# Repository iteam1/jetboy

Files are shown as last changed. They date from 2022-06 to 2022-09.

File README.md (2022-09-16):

 

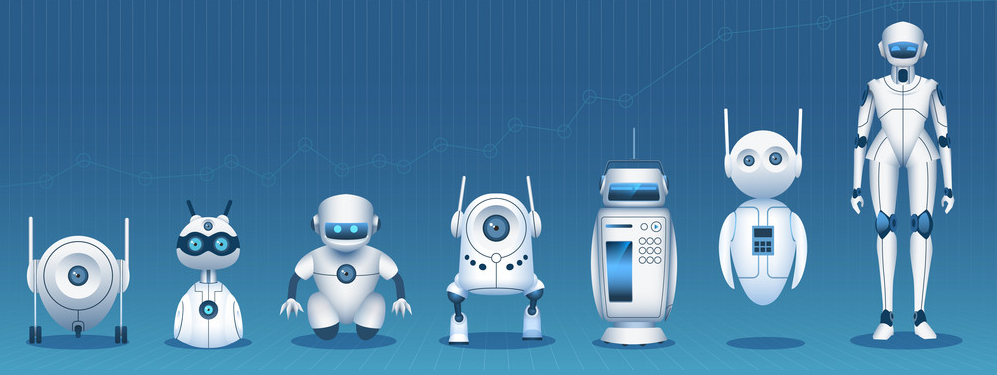
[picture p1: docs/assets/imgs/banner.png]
banner


### robot-jetboy

#### Quick-guide

**Step1** clone this repo `git clone git@github.com:iteam1/robot-jetboy.git`

**Step2** go to [init](/init) then follow the instruction for setting up the repository.

**Step3** run the entry point script `sudo bash root.sh --help`

To access the robot remotely linux-linux `ssh jetboy@<robot-internal-ip>` or [PuTTY](https://www.putty.org/)

*Note*

- [gpio.py](/gpio.py): control robot gpio

- [server.py](/server.py): build a local webserver for manually control

#### Online document

[offical-online-documents](https://iteam1.github.io/jetboy-docs/index-en.html)

#### Tools

|No|Tool|Description|
|---|---|---|
|1|[sublime-text](https://www.sublimetext.com/)|code editor|
|2|[diagrameditor](https://www.diagrameditor.com/)|drawing UML|
|3|[pixlr](https://pixlr.com/vn/x/)|design banner|
|4|[github](https://github.com/)|cloud platform for manage your project|
|5|[git](https://git-scm.com/)|control your repository|
|6|[ezgif](https://ezgif.com/maker)|ezgif maker|
|7|[symbolcopy](https://www.symbolcopy.com/)|get symbol character|
|8|[shields](https://shields.io/)|create your own git badges|
|9|[kleki](https://kleki.com/)|drawing sketch online|
    
#### References

[jetson-inference](https://github.com/dusty-nv/jetson-inference) | [examples](https://github.com/dusty-nv/jetson-inference/tree/master/examples) | [python](https://github.com/dusty-nv/jetson-inference/tree/master/python) | [plugins](https://github.com/dusty-nv/jetson-inference/tree/master/plugins) | [c](https://github.com/dusty-nv/jetson-inference/tree/master/c) | [convert to numpy array](https://github.com/dusty-nv/jetson-inference/issues/1118)

[libRealsense](https://github.com/IntelRealSense/librealsense) | [installLibrealsense](https://github.com/JetsonHacksNano/installLibrealsense)

[open3D](https://github.com/isl-org/Open3D)

[face-recognition](https://github.com/ageitgey/face_recognition)

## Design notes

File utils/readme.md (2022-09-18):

### repo utils

|Program|Description|Comment|
|---|---|---|
|[test_serial.py](/utils/test_serial.py)|test serial-communication with microcontroller arduino-nano, connect to serial port example: `COM4` on Windows or `dev/ttyUSB0`, give permission for serial port `sudo chmod a+rw /dev/ttyUSB0`|refer to embeded code [test_uart](https://github.com/iteam1/robot-jetboy/tree/main/embed/test_uart),[uart2uart](https://github.com/iteam1/robot-jetboy/tree/main/embed/uart2uart)|
|[read_db.py](/utils/read_db.py)|test serial-communication with arudino chip|`python3 -n 1 /utils/read_db.py`|
|[stream_d455.py](/utils/stream_d455.py)|test stream depth camera d455 by pyrealsense and opencv|depend on module [realsense_depth.py](/utils/realsense_depth.py)|
|[stream_cam.py](/utils/stream_cam.py)|test stream serial camera by opencv|list all camera on Linux `ls /dev/video*`|
|[test_sensor.py](/utils/test_sensor.py)|test ultra-sonic sensors signal||
|[rplidar.py](/utils/rplidar.py)|get info from serial RPlidar A1||
|[track_marker.py](/utils/track_marker.py)|control robot follow a target aruco-marker's id|required opencv-contrib for using aruco module, this package is no longer used in this repo, for reference purposes only|
|[view_cloud.py](/utils/view_cloud.py)|view a single point cloud file `.ply` file captured by depth camera||
|[pyrealsense2](/utils/pyrealsense2)|this is not a util program, if you want to use pyrealsense package installed by build from source C, you have to add this floder into the directory where you store the util program use pyrealsense, similar [realsense_depth.py](/utils/realsense_depth.py)||
|[test_motor.py](/utils/test_motor.py)|test motor controller||
|[detect_ports.py](/utils/detect_ports.py)|identify multi serial ports|list all port on linux `ls /dev/ttyUSB*`|
|[gpio_control.py](/utils/gpio_control.py)|intergate arm, emoled, and motor into a object and control via input||
|[face_rec.py](/utils/face_rec.py)|test face recognition function|`dlib` error,install command [here](https://github.com/iteam1/robot-jetboy/tree/main/init)|
|[blur_face_webcam.py](/utils/blur_face_webcam.py)|blur face by face_recognition||

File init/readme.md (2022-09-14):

### initialize-guide

**step1**: install a code-editor `bash sublime-text.sh`.

**step2**: install `python3-pip` package: `sudo apt-get update & sudo apt-get install python3-pip`.

**step3**: install python packages virtual enviroment `pip3 install virtualenv`.

**step4**: install pyrealsense for using D455 depth camera `bash pyrealsense.sh`. pyrealsense can not install normally by `pip3`.

**step5**: install opencv `sudo apt-get install python3-opencv` (stable version)

**step6**: install face-recognition `bash face_recognition.sh`.[issuses](http://www.open3d.org/docs/release/arm.html)

**step7**: install jetson-inference by this command `bash jetson-inference.sh`, **run it outsize this repo**.

**step8** : install open3d. [help](https://github.com/isl-org/Open3D/issues/2606#issuecomment-742760659) or Open3D provides experimental support for 64-bit ARM architecture (arm64 or aarch64) on Linux and macOS (Apple Silicon). refer to [ARM support](http://www.open3d.org/docs/release/arm.html).But first try this command:
     
     python3 -m pip install --upgrade pip
     sudo pip3 install open3d==0.13.0

**step9**: install the other required packages by in [requirements.txt](/init/requirements.txt) `pip3 install -r requirements.txt`.

these packages can be install normally by `pip3 install [package_name]`, [requirements.txt](/init/requirements.txt) contain the main packages and their dependencies, bellow is main packages you can install them manually by `pip3 install [package_name]`.

     flask
     flask_sqlalchemy
     sqlite3
     numpy
     pyserial

- export packages into requirements.txt: `pip3 freeze > requirements.txt`.

*Notes:* All packages,libraries and dependencies must be install in gobal. `RPi.GPIO` is build-in package and only can be install on embedded-hardwares like jetson-board or raspberry-board.

**bash-scripts table**

|No|Script|Description|Comment|
|---|---|---|---|
|01|[sublime-text.sh](/init/sublime-text.sh)|install code editor sublime-text|*required*|
|02|[pyrealsense.sh](/init/pyrealsense.sh)|install pyrealsense python library|*required*|
|03|[face_recognition.sh](/init/face_recognition.sh)|install pyrealsense python library|*required*|
|04|[opencv-contrib.sh](/init/opencv-contrib.sh)|install opencv-contrib version for jetson-nano, build from source||
|05|[tensorflow.sh](/init/tensorflow.sh)|install tensorflow for jetson-nano||
______

#### init database

the database `sqlite3` is already there in the repo, but if you lost it, in `/utils` folder Run python script for generate a sqlite database: `python3 robot/gendata.py`, this command will create a datbase and a table. Then open terminal and add a row into that table:

	from robot import db
	from robot.models import Robot
	robot = Robot()
	db.session.add(robot)
	db.session.commit()
______

#### setup for lidar sensor

add permission for connecting to serial port `/dev/ttyUSB0` permission denied, `username =  jetboy`. `portname = /dev/ttyUSB0` by: `sudo usermod -a -G dialout <username> & sudo chmod a+rw <portname>`

connect to lidar serial port:

     sudo su
     cd /
     cd dev
     chown <username> ttyUSB0

or:

     cd /dev
     ls t*
     sudo usermod -a -G dialout $USER
______

#### backup and restore os-system

go to `\` as `super user`

     sudo su
     cd /

run command to create backup.tar.gz file

     sudo tar czf /backup.tar.gz\
      --exclude=/backup.tar.gz\
      --exclude=/bin\
      --exclude=/boot\
      --exclude=/dev\
      --exclude=/dist-packages\
      --exclude=/lib\
      --exclude=/lost+found\
      --exclude=/media\
      --exclude=/mnt\
      --exclude=/opt\
      --exclude=/proc\
      --exclude=/root\
      --exclude=/run\
      --exclude=/sbin\
      --exclude=/snap\
      --exclude=/srv\
      --exclude=/sys\
      --exclude=/tmp\
      --exclude=/usr\
      --exclude=/var\
      /

make sure you are root and that you and the backup file are in the root of the filesystem `tar xvpfz backup.tar.gz -C /`
______

#### access robot remotely

- you can use ssh software like PuTTY or if using linux, this os-system is already support ssh into another linux-machine: `ssh [machine_name]@[machine_lan_ip]`, example: `ssh jetboy@192.168.1.9`
______

#### give permission for serial port

if you want to gibve permission for serial port `/dev/ttyUSB0`: `sudo chmod a+rw /dev/ttyUSB0`

### check JetPack version

if you want to check your JetPack verison `sudo apt-cache show nvidia-jetpack`
for the version specifically `sudo apt-cache show nvidia-jetpack | grep "Version"`

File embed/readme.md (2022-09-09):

### embedded source code

|No|Program|Description|Comment|
|---|---|---|---|
|01|[CODE_ARM_ROBOT2](/embed/CODE_ARM_ROBOT2)|robot arm arduino-nano source code|version2|
|02|[CODE_ARM_ROBOT3](/embed/CODE_ARM_ROBOT3)|robot arm arduino-nano source code|version3|
|03|[sketch_nov26a](/embed/sketch_nov26a)|arudino-nano read ultra sensors's signal||
|04|[sketch_oct31g](/embed/sketch_oct31g)|test motor driver BTS960||
|05|[test_uart](/embed/test_uart)|test uart commnication between main board and chip arduino by builtin-port|refer to python code [test_serial.py](https://github.com/iteam1/robot-jetboy/blob/main/utils/test_serial.py)|
|06|[uart2uart](/embed/uart2uart)|test uart commnication between main board and chip arduino by softserial library|refer to python code [test_serial.py](https://github.com/iteam1/robot-jetboy/blob/main/utils/test_serial.py)|
|07|[TEST_SERVO_STEP_EEPROM_Serial_Timer2US](/embed/TEST_SERVO_STEP_EEPROM_Serial_Timer2US)|test step-motor with timer-interrupt||
|08|[CODE_ARM_ROBOT](/embed/CODE_ARM_ROBOT)|robot arm arduino-nano source code but not be used anymore||
|09|[Blink](/embed/Blink)|test arduino nano clip with basic program blink build-in led||
|10|[Sweep](/embed/Sweep)|test RC servo, control servo rotate from a minimum angle to maximum angle||
|11|[Stepper](/embed/Stepper)|test Step motor, control rotate from a minimum angle to maximum angle||
|12|[Stepper2](/embed/Stepper2)|test Step motor, control rotate from a minimum angle to maximum angle by delayMicrosecond||
|13|[Code_LED_64_RGB](/embed/Code_LED_64_RGB),dependence [NeoPixel](https://github.com/adafruit/Adafruit_NeoPixel)|Emotional LED||
|14|[emoled](/embed/emoled)|Emotional LED customized,dependence [NeoPixel](https://github.com/adafruit/Adafruit_NeoPixel)|using|
|15|[arm](/embed/arm)||using|

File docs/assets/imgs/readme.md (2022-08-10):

|No|Image|Description|Comment|
|---|---|---|---|
|01|[banner](/docs/assets/imgs/banner.png)|repo banner|---|
|02|[img1](/docs/assets/imgs/img1.png)|Jetson Nano B01 pinout|---|
|03|[img2](/docs/assets/imgs/img2.png)|Jetson Nano B01 layout|---|
|04|[img3](/docs/assets/imgs/img3.png)|Arduino Nano control robot's arm|---|
|05|[img4](/docs/assets/imgs/img4.png)|Robot's arm wiring diagram|[detail](https://nshopvn.com/product/mach-dieu-khien-dong-co-buoc-tb6600-4-0a-942vdc/)|
|06|[img5](/docs/assets/imgs/img5.png)|Robot's motor driver|[detail](https://nshopvn.com/product/mach-dieu-khien-dong-co-dc-bts7960-43a-1-dong-co/)|
|07|[img6](/docs/assets/imgs/img6.png)|TB6600 step motor driver|[detail](https://nshopvn.com/product/mach-dieu-khien-dong-co-buoc-tb6600-4-0a-942vdc/)|
|08|[img7](/docs/assets/imgs/img7.png)|Voltage-Ampere metter 5-28VDC with internal source|---|
|09|[img8](/docs/assets/imgs/img8.png)|Voltage-Ampere metter 0-100VDC with external source|---|
|10|[img9](/docs/assets/imgs/img9.png)|schematic|---|
|11|[img10](/docs/assets/imgs/img10.png)|PL2303-Arduino Serial communication|---|
|12|[img11](/docs/assets/imgs/img11.png)|Emotional LED|---|

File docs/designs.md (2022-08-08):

### UMLs and sketchs of the repo

this table bellow give you the overview about repo's sketchs and UML.

|No|Name|Description|Comment|
|---|---|---|---|
|01|[sketch1](/docs/assets/sketchs/sketch1.pdf)|robot's electrical system overview|---|
|02|[uml1](/docs/assets/umls/UML1.xml)|describe how local-server, gpio module local database workflow|open with [diagrameditor](https://www.diagrameditor.com/)|
|03|[uml2](/docs/assets/umls/uml2.xml)|describe testing procedure|---|
|04|[uml3](/docs/assets/umls/uml3.xml)|describe how to control continously moving|this idea is not apply right now|
|05|uml4|describe how gpio-controller and  database work|---|
|06|[sketch2](/docs/assets/sketchs/sketch2.pdf)|robot's arm schematic,coordinate|---|
|07|[sketch2.1](/docs/assets/sketchs/sketch2.1.pdf)|robot's arm driver wiring,setting up|---|
|08|uml5|robot's arm workflow,protocol|---|
|09|sketch3|describe robot's motors,wiring,workflow,protocol|---|
|10|sketch4|describe robot's emotional-led,wiring,workflow,protocol|---|
|11|sketch5|describe robot's sensors,wiring,workflow,protocol|---|

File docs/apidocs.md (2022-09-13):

### APIdocs

1. [Home](#Home)
2. [Stream color frame](#Stream-color-frame)
3. [Stream depth frame](#Stream-depth-frame)
4. [Stream both frames](#Stream-both-frames)
5. [Manual](#Manual)
6. [Content](#Content)
7. [Emotion](#Emotion)
8. [Image](#Image)
9. [Estop](#Estop)
10. [Capture image](#Capture-image)
11. [Capture pointcloud](#Capture-pointcloud)
12. [Shutdown](#Shutdown)
13. [Get camera](#Get-camera)
14. [Face recogition](#Face-recognition)

## Home
[go back](#APIdocs)
<details><summary>click to expand</summary>
<p>

  Home page
* **URL:** `/`
* **Method:** `GET`
*  **URL Params:**
   **Required:**`None`
   **Optional:**`None`
* **Query Params:**`None`
* **Success Response:**
  * **Code:** 200 <br />
    **Content:** `home.html`
* **Error Response:**
  * **Code:** `None` <br />
    **Content:** `None`
* **Sample Call:**
* **Notes:**
  Check server is alive or not.
</p>
</details>

## Stream color frame
[go back](#APIdocs)
<details><summary>click to expand</summary>
<p>

  Response color frame from depth camera
* **URL:** `/color`
* **Method:** `GET`
*  **URL Params:**
   **Required:**`None`
   **Optional:**`None`
* **Query Params:**`None`
* **Success Response:**
  * **Code:** `None` <br />
    **Content:** streaming color frame
* **Error Response:**
  * **Code:** `None` <br />
    **Content:** `None`
* **Sample Call:**
* **Notes:**
  Get color frame of depth camera real-time
</p>
</details>

## Stream depth frame
[go back](#APIdocs)
<details><summary>click to expand</summary>
<p>

  Response depth frame from depth camera
* **URL:** `/depth`
* **Method:** `GET`
*  **URL Params:**
   **Required:**`None`
   **Optional:**`None`
* **Query Params:**`None`
* **Success Response:**
  * **Code:** `None` <br />
    **Content:** streaming depth frame
* **Error Response:**
  * **Code:** `None` <br />
    **Content:** `None`
* **Sample Call:**
* **Notes:**
  Get depth frame of depth camera real-time
</p>
</details>

## Stream both frames
[go back](#APIdocs)
<details><summary>click to expand</summary>
<p>

  Response depth frame and color frame stack together
* **URL:** `/both`
* **Method:** `GET`
*  **URL Params:**
   **Required:**`None`
   **Optional:**`None`
* **Query Params:**`None`
* **Success Response:**
  * **Code:** `None` <br />
    **Content:** depth frame and color frame of depth camera
* **Error Response:**
  * **Code:** `None` <br />
    **Content:** `None`
* **Sample Call:**
* **Notes:**
  Get depth frame and color frame of depth camera real-time
</p>
</details>

## Manual
[go back](#APIdocs)
<details><summary>click to expand</summary>
<p>

  Return a GUI as manual panel for controlling
* **URL:** `/manual`
------
* **Method:** `GET`
*  **URL Params:**
   **Required:**`None`
   **Optional:**`None`
* **Query Params:**`None`
* **Success Response:**
  * **Code:** 200 <br />
    **Content:** `manual.html`
* **Error Response:**
  * **Code:** `None` <br />
    **Content:** `None`
* **Sample Call:**
* **Notes:**
  `estop` value in database will be readed and update in `manual.html` template as by `jinja2`
------
* **Method:** `POST`
*  **URL Params:**
   **Required:**`None`
   **Optional:**`None`
* **Query Params:**`None`
* **Web Form:**
```
<form action = "{{ url_for('manual') }}" method = 'POST'>
  <input type = 'hidden' name = 'command' id = 'command'  value = [your-command]>
  <button class="btn btn-primary">&#8593;</button>
</form>
```
* **Success Response:**
  * **Code:** 301 <br />
    **Content:** Redirect to `manual.html`
* **Error Response:**
  * **Code:** 401 <br />
    **Content:** 401,Command Not Found
* **Sample Call:**
* **Notes:**
  `estop` value in database will be readed and update in `manual.html` template as by `jinja2`
</p>
</details>

## Content
[go back](#APIdocs)
<details><summary>click to expand</summary>
<p>

  Update content in database
* **URL:** `/content`
* **Method:** `POST`
*  **URL Params:**
   **Required:**`None`
   **Optional:**`None`
* **Query Params:**`None`
* **Web Form:**
```
 <form action = "{{ url_for('content') }}" method = 'POST'>
  <input class="form-control form-control-lg" type="text" placeholder = "What you wanna say?" name = "content">
  <small class="form-text text-muted">.</small>     
  <button type="submit" class="btn btn-primary mb-2">say it!</button>
</form> 
```
* **Success Response:**
  * **Code:** 200 <br />
    **Content:** Render `manual.html` template
* **Error Response:**
  * **Code:** `None` <br />
    **Content:** `None`
* **Sample Call:**
* **Notes:**
  `estop` value in database will be readed and update in `manual.html` template as by `jinja2`
</p>
</details>

## Emotion
[go back](#APIdocs)
<details><summary>click to expand</summary>
<p>

  Update Emotiton in database
* **URL:** `/emotion`
* **Method:** `POST`
*  **URL Params:**
   **Required:**`None`
   **Optional:**`None`
* **Query Params:**`None`
* **Web Form:**
```
<form action = "{{ url_for('emotion') }}" method = 'POST'>
  <input type = 'hidden' name = 'emotion' value = '[your-emotion]'>
  <button type="submit" class="btn btn-secondary" style="font-size:50px">&#128564;</button>
</form>
```
* **Success Response:**
  * **Code:** 200 <br />
    **Content:** Render `manual.html` template
* **Error Response:**
  * **Code:** `None` <br />
    **Content:** `None`
* **Sample Call:**
* **Notes:**
  `estop` value in database will be readed and update in `manual.html` template as by `jinja2`,emotion display a .gif
</p>
</details>

## Image
[go back](#APIdocs)
<details><summary>click to expand</summary>
<p>

  Update Image in database
* **URL:** `/image`
* **Method:** `POST`
*  **URL Params:**
   **Required:**`None`
   **Optional:**`None`
* **Query Params:**`None`
* **Web Form:**
```
<form action = "{{ url_for('image') }}" method = 'POST'>
  <input type = 'hidden' name = 'image' value = 'straightface'>
  <button type="submit" class="btn btn-secondary" style="font-size:50px">&#128528;</button>
</form>
```
* **Success Response:**
  * **Code:** 200 <br />
    **Content:** Render `manual.html` template
* **Error Response:**
  * **Code:** `None` <br />
    **Content:** `None`
* **Sample Call:**
* **Notes:**
  `estop` value in database will be readed and update in `manual.html` template as by `jinja2`, image display a .png or .jpg file.
</p>
</details>

## Estop
[go back](#APIdocs)
<details><summary>click to expand</summary>
<p>

  Update estop value in database, if estop=0 update estop=1 else udpate estop=0
* **URL:** `/estop`
* **Method:** `POST`
*  **URL Params:**
   **Required:**`None`
   **Optional:**`None`
* **Query Params:**`None`
* **Web Form:**
```
<form action = "{{ url_for('estop') }}" method = 'POST'>
  <small class="form-text text-muted">.</small>
  <p class = 'text-center'>
      {% if estop == True %}
          <button type="Estop" class="btn btn-danger mb-4">ESTOP</button>
      {% else %}
          <button type="Estop" class="btn btn-primary mb-6">ESTOP</button>
      {% endif %}
  </p>
</form>
```
* **Success Response:**
  * **Code:** 200 <br />
    **Content:** Render `manual.html` template
  * **Code:** 201 <br />
    **Content:** Render `manual.html` template
* **Error Response:**
  * **Code:** `None` <br />
    **Content:** `None`
* **Sample Call:**
* **Notes:**
  Color of estop button will change, blue if estop=0 red if estop=1
</p>
</details>

## Capture image
[go back](#APIdocs)
<details><summary>click to expand</summary>
<p>

  Capture current frame of robot's camera
* **URL:** `/capture_img`
* **Method:** `POST`
*  **URL Params:**
   **Required:**`None`
   **Optional:**`None`
* **Query Params:**`None`
* **Web Form:**
```
<form action = "{{ url_for('capture_img') }}" method = 'POST'>
    <input type = 'hidden' name = 'capture image'>
    <button class="btn btn-primary mb-2">cap img</button>
</form>
```
* **Success Response:**
  * **Code:** 200 <br />
    **Content:** Render `manual.html` template
* **Error Response:**
  * **Code:** `None` <br />
    **Content:** `None`
* **Sample Call:**
* **Notes:**
  `estop` value in database will be readed and update in `manual.html` template as by `jinja2`
</p>
</details>

## Capture pointcloud
[go back](#APIdocs)
<details><summary>click to expand</summary>
<p>

  Capture current pointcloud (depth-frame) of robot's camera
* **URL:** `/capture_pointcloud`
* **Method:** `POST`
*  **URL Params:**
   **Required:**`None`
   **Optional:**`None`
* **Query Params:**`None`
* **Web Form:**
```
<form action = "{{ url_for('capture_pointcloud') }}" method = 'POST'>
  <input type = 'hidden' name = 'capture pointcloud'>
  <button class="btn btn-primary mb-2">cap pointcloud</button>
</form>
```
* **Success Response:**
  * **Code:** 200 <br />
    **Content:** Render `manual.html` template
* **Error Response:**
  * **Code:** `None` <br />
    **Content:** `None`
* **Sample Call:**
* **Notes:**
  `estop` value in database will be readed and update in `manual.html` template as by `jinja2`
</p>
</details>

## Shutdown
[go back](#APIdocs)
<details><summary>click to expand</summary>
<p>

  Shutdown robot's local flask server
* **URL:** `/shutdown`
* **Method:** `POST`
*  **URL Params:**
   **Required:**`None`
   **Optional:**`None`
* **Query Params:**`None`
* **Web Form:**
```
<form action = "{{ url_for('shutdown') }}" method = 'POST'>
  <button class="btn btn-danger mb-2">shutdown server</button>
</form>
```
* **Success Response:**
  * **Code:** 200 <br />
    **Content:** 'Server shutting down'
* **Error Response:**
  * **Code:** `None` <br />
    **Content:** `None`
* **Sample Call:**
* **Notes:** `None`
</p>
</details>

## Get camera
[go back](#APIdocs)
<details><summary>click to expand</summary>
<p>

  Response serial-camera frame
* **URL:** `/camera`
* **Method:** `GET`
*  **URL Params:**
   **Required:**`None`
   **Optional:**`None`
* **Query Params:**`None`
* **Success Response:**
  * **Code:** `None` <br />
    **Content:** streaming frame of serial-camera
* **Error Response:**
  * **Code:** `None` <br />
    **Content:** `None`
* **Sample Call:**
* **Notes:**
  Get color `RGB` frame of serial-camera real-time, function's name in `routes.py` `get_cam`, Only one device can get the response, An other need to wait until finish, can not share `cv2.VideoCapture()` streaming data
</p>
</details>

## Face recognition
[go back](#APIdocs)
<details><summary>click to expand</summary>
<p>

  Response face-recognition detected by serial-camera
* **URL:** `/faces`
* **Method:** `GET`
*  **URL Params:**
   **Required:**`None`
   **Optional:**`None`
* **Query Params:**`None`
* **Success Response:**
  * **Code:** `None` <br />
    **Content:** streaming detected face on frame of serial-camera
* **Error Response:**
  * **Code:** `None` <br />
    **Content:** `None`
* **Sample Call:**
* **Notes:**
  face-recognition application, function's name in `routes.py` `get_face`, Only one device can get the responsem An other need to wait until finish, can not share `cv2.VideoCapture()` streaming data
</p>
</details>

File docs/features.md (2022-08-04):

## robot's features & change logs

new features and change logs will be write down in this document

### 31-July-22

**1/ Power supply and electrical system**

- Main power supply is 6Ah-12VDC litium battery (chargeable)
- Voltage and Current metter

*Note:* the current consumption can be increase when boot up, `over current throtted` warning will display on screen and yellow power led on main board blink, that's beacause depth camera d455 consump alot current of main-board jetson nano. The total current can between 0-10 Ampere if only running main-board and 20-30 Ampere when robot's motor run.

**2/ Visual intelligence**

- Depth camera D455 (Intel Realsense)

      -Components	
            - Intel RealSense D4
            - Module Intel RealSense D450
            - Bosch BMI055 IMU
      - Viewspace	86° × 57° (+/- 3°)
      - Resolution	
            - 1280 × 720 @ 30fps
            - 848 × 480 @ 90fps
      - Frame per second:	Up to 90 fps
      - Minimum Depth Distance (Min-Z: 40 cm
      - Sensor Shutter Type: Global Shutter
      - Recommended Range: From 0.4 to 6 m
      - Dimensions: 124 mm × 26 mm × 29 mm
      - Connection Type: USB-C* 3.1 Gen 1

**3/ Manual control**

A local web-server by python web framework Flask help user can control robot manually, streaming camera frame,etc. Check [apidocs](/docs/apidocs.md) for more information.

**4/ GPIO control**

Module `gpio.py` contain class for controlling motor, arm,etc. 

### 31-August-22

**1/ Power supply and electrical system**

- Expand power from 6Ah-12VDC into 12Ah-VDC

- Separate main-board power source and the others (actuators, sensors,etc.)
 
**2/ Hardware**

**3/ Create 3d map**

Create a 3D map with [Open3D](http://www.open3d.org/docs/release/getting_started.html#python) and moving-log

**4/ Visual intelligence**

Apply machine learning vision models by [jetson-inference](https://github.com/dusty-nv/jetson-inference)

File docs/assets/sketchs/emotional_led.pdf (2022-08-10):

0 | 1 | 2 | 3 | 4 | 5 | 6 | 7 | 0 | 1 | 2 | 3 | 4 | 5 | 6 | 7
8 | 9 | 10 | 11 | 12 | 13 | 14 | 15 | 8 | 9 | 10 | 11 | 12 | 13 | 14 | 15
16 | 17 | 18 | 19 | 20 | 21 | 22 | 23 | 16 | 17 | 18 | 19 | 20 | 21 | 22 | 23
24 | 25 | 26 | 27 | 28 | 29 | 30 | 31 | 24 | 25 | 26 | 27 | 28 | 29 | 30 | 31
32 | 33 | 34 | 35 | 36 | 37 | 38 | 39 | 32 | 33 | 34 | 35 | 36 | 37 | 38 | 39
40 | 41 | 42 | 43 | 44 | 45 | 46 | 47 | 40 | 41 | 42 | 43 | 44 | 45 | 46 | 47
48 | 49 | 50 | 51 | 52 | 53 | 54 | 55 | 48 | 49 | 50 | 51 | 52 | 53 | 54 | 55
56 | 57 | 58 | 59 | 60 | 61 | 62 | 63 | 56 | 57 | 58 | 59 | 60 | 61 | 62 | 63
0 | 1 | 2 | 3 | 4 | 5 | 6 | 7 | 0 | 1 | 2 | 3 | 4 | 5 | 6 | 7
8 | 9 | 10 | 11 | 12 | 13 | 14 | 15 | 8 | 9 | 10 | 11 | 12 | 13 | 14 | 15
16 | 17 | 18 | 19 | 20 | 21 | 22 | 23 | 16 | 17 | 18 | 19 | 20 | 21 | 22 | 23
24 | 25 | 26 | 27 | 28 | 29 | 30 | 31 | 24 | 25 | 26 | 27 | 28 | 29 | 30 | 31
32 | 33 | 34 | 35 | 36 | 37 | 38 | 39 | 32 | 33 | 34 | 35 | 36 | 37 | 38 | 39
40 | 41 | 42 | 43 | 44 | 45 | 46 | 47 | 40 | 41 | 42 | 43 | 44 | 45 | 46 | 47
48 | 49 | 50 | 51 | 52 | 53 | 54 | 55 | 48 | 49 | 50 | 51 | 52 | 53 | 54 | 55
56 | 57 | 58 | 59 | 60 | 61 | 62 | 63 | 56 | 57 | 58 | 59 | 60 | 61 | 62 | 63
0 | 1 | 2 | 3 | 4 | 5 | 6 | 7 | 64 | 65 | 66 | 67 | 68 | 69 | 70 | 71
8 | 9 | 10 | 11 | 12 | 13 | 14 | 15 | 72 | 73 | 74 | 75 | 76 | 77 | 78 | 79
16 | 17 | 18 | 19 | 20 | 21 | 22 | 23 | 80 | 81 | 82 | 83 | 84 | 85 | 86 | 87
24 | 25 | 26 | 27 | 28 | 29 | 30 | 31 | 88 | 89 | 90 | 91 | 92 | 93 | 94 | 95
32 | 33 | 34 | 35 | 36 | 37 | 38 | 39 | 96 | 97 | 98 | 99 | ## | 101 | 102 | 103
40 | 41 | 42 | 43 | 44 | 45 | 46 | 47 | 104 | 105 | 106 | 107 | ## | 109 | 110 | 111
48 | 49 | 50 | 51 | 52 | 53 | 54 | 55 | 112 | 113 | 114 | 115 | ## | 117 | 118 | 119
56 | 57 | 58 | 59 | 60 | 61 | 62 | 63 | 120 | 121 | 122 | 123 | ## | 125 | 126 | 127
0 | 1 | 2 | 3 | 4 | 5 | 6 | 7 | 64 | 65 | 66 | 67 | 68 | 69 | 70 | 71
8 | 9 | 10 | 11 | 12 | 13 | 14 | 15 | 72 | 73 | 74 | 75 | 76 | 77 | 78 | 79
16 | 17 | 18 | 19 | 20 | 21 | 22 | 23 | 80 | 81 | 82 | 83 | 84 | 85 | 86 | 87
24 | 25 | 26 | 27 | 28 | 29 | 30 | 31 | 88 | 89 | 90 | 91 | 92 | 93 | 94 | 95
32 | 33 | 34 | 35 | 36 | 37 | 38 | 39 | 96 | 97 | 98 | 99 | ## | 101 | 102 | 103
40 | 41 | 42 | 43 | 44 | 45 | 46 | 47 | 104 | 105 | 106 | 107 | ## | 109 | 110 | 111
48 | 49 | 50 | 51 | 52 | 53 | 54 | 55 | 112 | 113 | 114 | 115 | ## | 117 | 118 | 119
56 | 57 | 58 | 59 | 60 | 61 | 62 | 63 | 120 | 121 | 122 | 123 | ## | 125 | 126 | 127
0 | 1 | 2 | 3 | 4 | 5 | 6 | 7 | 0 | 1 | 2 | 3 | 4 | 5 | 6 | 7
8 | 9 | 10 | 11 | 12 | 13 | 14 | 15 | 8 | 9 | 10 | 11 | 12 | 13 | 14 | 15
16 | 17 | 18 | 19 | 20 | 21 | 22 | 23 | 16 | 17 | 18 | 19 | 20 | 21 | 22 | 23
24 | 25 | 26 | 27 | 28 | 29 | 30 | 31 | 24 | 25 | 26 | 27 | 28 | 29 | 30 | 31
32 | 33 | 34 | 35 | 36 | 37 | 38 | 39 | 32 | 33 | 34 | 35 | 36 | 37 | 38 | 39
40 | 41 | 42 | 43 | 44 | 45 | 46 | 47 | 40 | 41 | 42 | 43 | 44 | 45 | 46 | 47
48 | 49 | 50 | 51 | 52 | 53 | 54 | 55 | 48 | 49 | 50 | 51 | 52 | 53 | 54 | 55
56 | 57 | 58 | 59 | 60 | 61 | 62 | 63 | 56 | 57 | 58 | 59 | 60 | 61 | 62 | 63

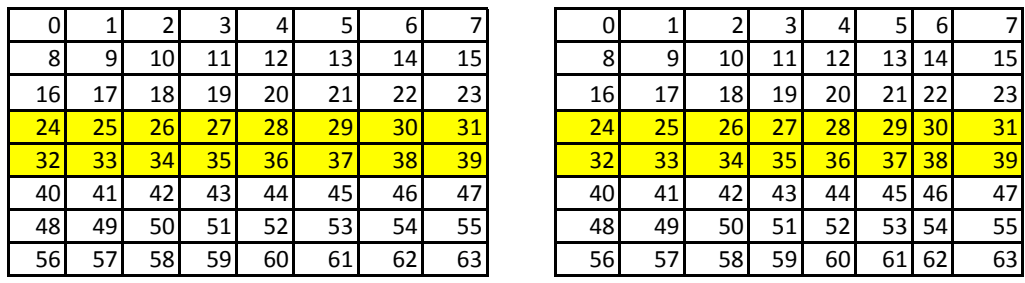
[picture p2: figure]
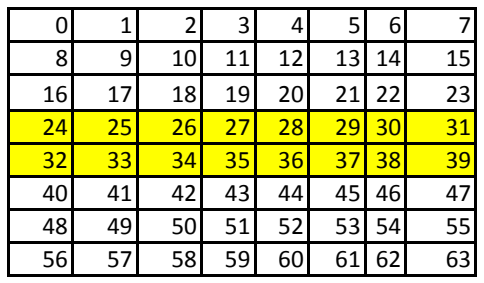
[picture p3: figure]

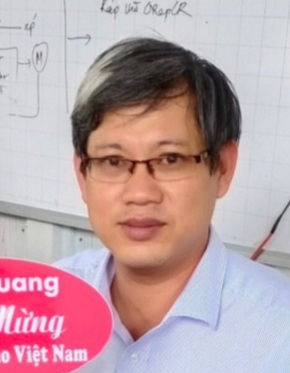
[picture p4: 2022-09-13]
utils/faces/cuong.png

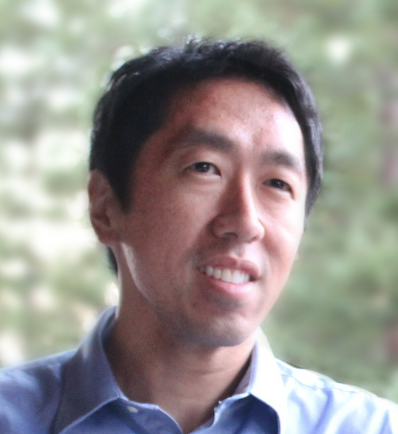
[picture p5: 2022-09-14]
faces/Andrew_Ng.png

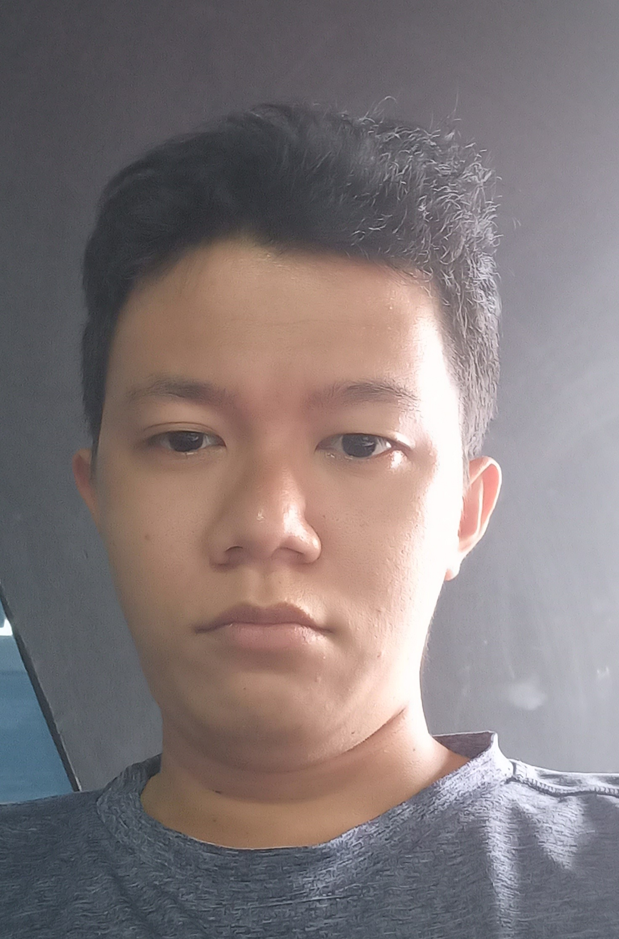
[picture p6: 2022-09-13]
utils/faces/loc.png

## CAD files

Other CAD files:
docs/assets/sketchs/assembly.dwg
docs/assets/sketchs/cover/cabinet.dwg
docs/assets/sketchs/cut.dwg
docs/assets/sketchs/head/head.dwg
docs/assets/sketchs/wheel/banh_xe.dwg
docs/assets/sketchs/cover/cover.dwg
docs/assets/sketchs/head/trang.dwg
docs/assets/sketchs/banh_xe.dwg
docs/assets/sketchs/head/trongden.dwg
docs/assets/sketchs/tam4.dwg
docs/assets/sketchs/cad.dwg
docs/assets/sketchs/pin.dwg
docs/assets/sketchs/panel.dwg
docs/assets/sketchs/de.dwg
docs/assets/sketchs/tam3.dwg
docs/assets/sketchs/motor.dwg
docs/assets/sketchs/base.dwg
docs/assets/sketchs/tam2.dwg
docs/assets/sketchs/banh_lan.dwg
docs/assets/sketchs/tam1.dwg

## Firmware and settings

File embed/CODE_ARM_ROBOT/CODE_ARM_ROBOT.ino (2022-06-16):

#include <avr/io.h>
#include <avr/interrupt.h>
byte reload = 50;  //100us for interupt timer
int count = 0; //make a pulse for step motor if count == 8
unsigned long Tmoi,T_delay; // T_delay for delay function
#include <EEPROM.h>
#include <SoftwareSerial.h>
SoftwareSerial mySerial(11, 10); // create a serial object for uart communicate 11 = RX, 10 = TX
#include <Servo.h>
#include <string.h>
Servo sv4,sv3, sv2, sv1;  // create servo object to control a servo
#define motorInterfaceType 1
String s=""; // the framework string to communicate with main control board
int g1,g2,g3,g4; // useless
float tdcu[5]; // for storage previous RC angle 
float tdmoi[5]; // for storage new RC angle 
float h[4]; // for storage previous RC angle 
float denta[5]; // for storage the distance between set value of RC servo angle and previous one
// float tdcu1[5];
// float tdmoi1[5];
// float h1[5];
// float denta1[5];
int S1; // the value angle of servo 1 you received from framework
int S2; // the value angle of servo 2 you received from framework
int S3; // the value angle of servo 3 you received from framework
int S4; // the value angle of servo 4 you received from framework
int ST1; // the value angle of step motor you received from the framework
int STmoi = 0; // the new value of angle calculated by set pulse - current pulse
int STcu = 0; // the old value angle of step motor for comparing with new current value angle
int EN = 0; // working mode received from framework
int Xung_Xoay = 0; // the set pulse value
int dem = 0; // the current pulse value for comparing with Xung_Xoay
int S = 0; // the set value of gripping angle
byte Home = 0; // get 1 value if robot go home
boolean s1 = false; // limit switch
byte Run_Step = 0; // get value 1 if step motor is running, 0 if step stopped
String str; // the string framework
char buf[100]; // useless
int  chuoi[] = {
    20,90,90,90, //trang thai mat dinh
    110, 20,45, 140,   //Dua ra phia truoc
//    20, 90, 90, 90,    
//    110, 20,45, 140,   
//    20, 90, 90, 90
};
//unsigned long timer, timer1;
const int BT =  12; // button 
const int RES =  A0; // the potential meter
const int BZ =  A5; // buzzer
const int stepPin = 4; // make pulse for step motor
const int dirPin = 7; // direction for step motor pin
const int enPin = 8; // brake step motor pin

// move the robot to zero position
void setgoc();
void Run(int G1, int G2, int G3, int G4, int T, int Dir);
void setup() {
  
  // STEP1: Serial setup
  Serial.begin(9600); // Arduino internal serial
  mySerial.begin(9600); // your custom serial
  
  // STEP2: Pinmode setup
  pinMode(stepPin,OUTPUT); // init stepPin for step motor is output
  pinMode(dirPin,OUTPUT); // init dirPin for step motor direction is output
  pinMode(enPin,OUTPUT); // init enable for step motor is output, BRAKE control
  pinMode(BZ,OUTPUT); // buzzer
  pinMode(BT,INPUT); // button
  pinMode(RES,INPUT); // potential resistor
  pinMode(13, OUTPUT); // led builtin
  digitalWrite(13,0);
  attachInterrupt(0, Ngat, FALLING);
  Serial.println("1");
  
  // STEP3: Timer setup
  cli(); // init timer, disable all interupt before you done setup
  Serial.println("2");
  TCCR0B = 0; 
  OCR2A = reload;
  TCCR2A = 1<<WGM21;
  TCCR2B = ((1<<CS21) | (1<<CS20));//1<<CS22)
  TIMSK2 = (1<<OCIE2A);
  Serial.println("3");
  sei();
  Serial.println("4");
  
  // STEP4: brake and buzzer setup
  digitalWrite(enPin,1); //0 la thang, 1 la nha
  digitalWrite(BZ,0);
  
  // STEP5: RC servo setup
  sv4.attach(3);  // goc tang la kep lai
  sv3.attach(5);  // goc tang la gap vao
  sv2.attach(6);  //goc giam la dua ra
  sv1.attach(9);  //goc tang la dua ra
  setgoc();
  
  // STEP6: set grip angle, push the button 
  if(digitalRead(BT) == 0) // if the button is pushed
  {
    // activate the buzzer 2 time for announcement
    digitalWrite(BZ,1);
    Delay(1000); // delay by custom function
    digitalWrite(BZ,0);
    Delay(2000);
    digitalWrite(BZ,1);
    Delay(1000);
    digitalWrite(BZ,0);
    Delay(10000);
    // wait until you release the button
    while(digitalRead(BT) == 0); // if the condition is true, continue loop
    // starting set the grip angle
    while(1)
    {
      int Val = analogRead(RES); // read the analog value of potential metter
      S = map(Val, 0, 1024, 0, 180); // map to range (0,180)
      Serial.println(S); // print out the value of grip angle
      sv4.write(S); // write the angle to gripping servo
      Delay(1000); // delay 1000ms 
      // if you have a correct angle, press the button to release
      if(digitalRead(BT) == 0)
      {
        EEPROM.write(0,S); // save the value to arduino eeprom, make sure this
        Delay(100);
        break; // jump out the while
      }
     }
  }
  // print out the gripping angle
  Serial.print("GT GOC: ");
  S = EEPROM.read(0);
  Serial.println(S);
  // return robot to zero position again
  setgoc();
  // announcement by buzzer that all setup is done
  digitalWrite(BZ,1);
  Delay(10000); //1s
  digitalWrite(BZ,0);
}

//------------------
void loop() {
  // if you received someting
  if (mySerial.available()) {
      // print out the content you received
      Serial.println("RX....");
      //90,20,80,90,90,1
      str = mySerial.readStringUntil('\n');
      Serial.println(str);
      /*
      convert a character string to double precision floating point value,
      get the sub string then convert it into integer
      */ 
      ST1 = atof(strtok(str.c_str(),","));
      S1 = atof(strtok(NULL,","));
      S2 = atoi(strtok(NULL,","));
      S3 = atoi(strtok(NULL,","));
      S4 = atoi(strtok(NULL,","));
      EN = atoi(strtok(NULL,","));
      Serial.println(EN); // print out the working mode
      /*
      Check the angle of step motor if it get over the limit then set it as the previous value
      */
      if(ST1 > 350 || ST1 < 0) {
          Serial.println("angle Step is over the limit");
          ST1 = STcu;// 
        }
      /*
      Check the working mode
      1: for go to specific position
      2: for go home
      3: robot go forward
      4: robot grip
      5: robot release
      */
      switch (EN) {
      case 1:    
        Run(ST1,S1,S2,S3,S4,600);
        // wait if xung_xoay of step motor still greater than dem
        while(Xung_Xoay >= dem){Serial.print(dem);Serial.print(" ");Serial.println(Xung_Xoay);}
        Run_Step = 0;
      break;
      
      case 2:   // TT mac dinh , go home and set angle STcu to 90
        Home = 1;
        Run(80,20,80,90,90,600);
        STcu = 90;
        // wait if xung_xoay of step motor still greater than dem
        while(Xung_Xoay >= dem){Serial.print(dem);Serial.print(" ");Serial.println(Xung_Xoay);}
    
        Serial.println("2");
      break;
      
      case 3:
        // robot go forward    
        Serial.println("3");
      break;
      
      case 4:    
        // robot grip
        Serial.println("4");  
      break;
      
      case 5:
        // robot release    
        Serial.println("5");
        
      break;
    }
  }
  // if you press the button then start to do a specific task

  if(digitalRead(BT) == 0)
  {
    Run(160,70,80,90,90,600);
    while(Xung_Xoay >= dem){Serial.print(dem);Serial.print(" ");Serial.println(Xung_Xoay);}
    Run(190,70,160,90,90,600);//190,70,160,90,90,1,A
    while(Xung_Xoay >= dem){Serial.print(dem);Serial.print(" ");Serial.println(Xung_Xoay);}
    Run(190,40,136,90,90,600);//190,40,136,90,90,1,A
    while(Xung_Xoay >= dem){Serial.print(dem);Serial.print(" ");Serial.println(Xung_Xoay);}
    Run(190,40,136,90,135,600);//190,40,136,90,135,1,A
    while(Xung_Xoay >= dem){Serial.print(dem);Serial.print(" ");Serial.println(Xung_Xoay);}
    Run(195,40,136,90,135,600);//195,40,136,90,135,1,A
    while(Xung_Xoay >= dem){Serial.print(dem);Serial.print(" ");Serial.println(Xung_Xoay);}
    Run(195,70,120,90,135,600);//195,70,120,90,135,1,A
    while(Xung_Xoay >= dem){Serial.print(dem);Serial.print(" ");Serial.println(Xung_Xoay);}
    Run(210,70,120,90,135,600);//210,70,120,90,135,1,A
    while(Xung_Xoay >= dem){Serial.print(dem);Serial.print(" ");Serial.println(Xung_Xoay);}
    Run(170,70,120,90,135,600); //170,70,120,90,135,1,A
    while(Xung_Xoay >= dem){Serial.print(dem);Serial.print(" ");Serial.println(Xung_Xoay);}
    Run(190,70,120,90,135,600);//190,70,120,90,135,1,A
    while(Xung_Xoay >= dem){Serial.print(dem);Serial.print(" ");Serial.println(Xung_Xoay);}
    Run(190,70,120,110,135,600); //190,70,120,110,135,1,A
    while(Xung_Xoay >= dem){Serial.print(dem);Serial.print(" ");Serial.println(Xung_Xoay);}
    Run(190,70,120,70,135,600); //    190,70,120,170,135,1,A
    while(Xung_Xoay >= dem){Serial.print(dem);Serial.print(" ");Serial.println(Xung_Xoay);}
    Run(195,40,136,90,135,600); //195,40,136,90,135,1,A
    while(Xung_Xoay >= dem){Serial.print(dem);Serial.print(" ");Serial.println(Xung_Xoay);}
    Run(190,40,136,90,135,600); //190,40,136,90,135,1,A
    while(Xung_Xoay >= dem){Serial.print(dem);Serial.print(" ");Serial.println(Xung_Xoay);}
    Run(190,40,136,90,90,600); //190,40,136,90,90,1,A
    while(Xung_Xoay >= dem){Serial.print(dem);Serial.print(" ");Serial.println(Xung_Xoay);}
    Run(190,80,136,90,90,600); //190,80,160,90,90,1,A
    while(Xung_Xoay >= dem){Serial.print(dem);Serial.print(" ");Serial.println(Xung_Xoay);}
    Run(90,20,80,90, 90,600);//90,20,80,90, 90,600
    while(Xung_Xoay >= dem){Serial.print(dem);Serial.print(" ");Serial.println(Xung_Xoay);}
    
    Run_Step = 0;
    Delay(50000); 
    digitalWrite(enPin,1);
  }
}
// specific interupt function each 100us...................
ISR(TIMER2_COMPA_vect)
{
  count++; // count this var for create a pulse
  T_delay++; // increase T_delay for time delay
  if(count >= 8) // if count == 8 then make a pulse
  {
    // if your motor is runing and dem < Xung_Xoay
    if( Run_Step == 1 && dem <= Xung_Xoay) {
      digitalWrite(stepPin,!digitalRead(stepPin)); 
    }
    dem++; // increase the current pulse after make a pulse
    count = 0; // reset count value
  }
  OCR2A = reload; // reload timer 
}
//----------------------------------------
void Run(int ST, int G1, int G2, int G3, int G4, int F)
{
  
  digitalWrite(enPin,0); // release the brake
  Run_Step = 1; // set run_step motor state  =1 
  count = 0; // reset the count var
  dem = 0; // reset the dem var
 
  STmoi= ST - STcu;// new step  = set step - current step
  Serial.print(ST);
  Serial.print("  ");
  Serial.print(STmoi);
  Serial.print("  ");
  Serial.println(STcu);
  if(STmoi > 0) {
    digitalWrite(dirPin,0);
    Xung_Xoay = STmoi * 89; // 89 = (16000/360)*2 vi 2 lan ngat moi dc 1 xung # 16000 = 1 round
    STcu = ST;
    Serial.println(" 1 ");
  }
  else if(STmoi < 0) {
    Home = 1;
    digitalWrite(dirPin,1);
    Xung_Xoay = abs(STmoi) * 89; // 46 = 23*2 vi 2 lan ngat moi dc 1 xung
    STcu = ST;
    Serial.println(" 2 ");
  }
  else {Xung_Xoay = -1; Run_Step = 0;Serial.println(" 3 ");}
  Serial.println(Xung_Xoay);
  
  tdmoi[0]=G1;
  tdmoi[1]=G2;
  tdmoi[2]=G3;
  tdmoi[3]=G4;
  Serial.println(Xung_Xoay);
  for(char r1=0; r1<4; r1++)
      {
        denta[r1] = tdmoi[r1]-tdcu[r1];
        h[r1] = denta[r1]*1.00/F;
      }
      Serial.println(Xung_Xoay);
      for(int r2=0; r2<F; r2++)
      {
            tdcu[0]=tdcu[0]+h[0];
            //
            tdcu[1]=tdcu[1]+h[1];
            //
            tdcu[2]=tdcu[2]+h[2];
            //
            tdcu[3]=tdcu[3]+h[3];
            sv1.write(tdcu[0]);
            sv2.write(tdcu[1]);
            sv3.write(tdcu[2]);
            sv4.write(tdcu[3]);
            Delay(10);
           
    }
    Serial.println(Xung_Xoay);
}
//--------------------------------------------
void setgoc()
{ 
    STcu=90;
  
   tdcu[0]=20;          //nhin tu trc, ben phai
   sv1.write(tdcu[0]);
   Serial.println("7");
   //
   tdcu[1]=80;
   sv2.write(tdcu[1]);
   //
   tdcu[2]=90;
   sv3.write(tdcu[2]);
   //
   tdcu[3]=90;
   sv4.write(tdcu[3]); 
Serial.println("8");
  Delay(10000);
    Serial.println("9");
}
void Ngat()
{
  if(Home == 1){ digitalWrite(enPin,1); Home = 0;}
}
void Delay(unsigned int T)  //T = 10000 = 1s
{
  T_delay = 0;
  while(T_delay < T){Serial.println(T_delay);}
}

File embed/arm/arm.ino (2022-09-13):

/*
 * https://nshopvn.com/product/mach-dieu-khien-dong-co-buoc-tb6600-4-0a-942vdc/
 * Kết nối:
          TB6600                  Arduino
           ENA+                     8-enPin
           DIR+                     7-dirPin
           PUL+                     4-stepPin
           ENA-                     GND
           DIR-                     GND
           PUL-                     GND

  A+ A- B+ B- kết nối với động cơ
  Nguồn đầu vào là 9V - 42V.
 */
# include <avr/io.h>
# include <avr/interrupt.h>
# include <EEPROM.h>
# include <Servo.h> // Servo lib
# include <SoftwareSerial.h> // External serial port

SoftwareSerial mySerial(11,10); // create a serial object for uart communicate 11=Rx,10=Tx
Servo sv1,sv2,sv3,sv4;  // robot's arm have 4 rc servo

int count = 0; // make counter count pulse of step motor

unsigned long Tdelay; // count tick-value of timer for delay function

const int BT = 12; // button on board
const int RES = A0; // the potential meter
const int BZ = A5; // buzzer
const int LED = 13; // buildtin led

const int stepPin = 4; // make pulse for step motor
const int dirPin = 7; // direction for step motor pin
const int enPin = 8; //brake step motor pin
const int rev = 1600;
bool in_run = false; // step motor is running, stop = false 

String Val = "";

bool myserial = true; // option to choice builtin serial or mySerial port

void setup() {

  //Serial setup
  Serial.begin(9600);
  mySerial.begin(9600);

  // init servo
  sv1.attach(9);  // attaches the servo on pin 9 to the servo object
  sv2.attach(6);
  sv3.attach(5);
  sv4.attach(3);

  // button, potential, buzzer
  pinMode(BT,INPUT); // button on board
  pinMode(RES,INPUT); // the potential meter
  pinMode(BZ,OUTPUT); // buzzer
  pinMode(LED,OUTPUT); // Led build in
  
  // Sets the two pins as Outputs
  pinMode(stepPin,OUTPUT); 
  pinMode(dirPin,OUTPUT);
  pinMode(enPin,OUTPUT);

  // brake and buzzer setup
  digitalWrite(enPin,1); // 0 is realse, 1 is brake
  digitalWrite(BZ,0); // 0 is off, 1 is buzz

  //store the value of counter into EEPROM
  EEPROM.write(0,count); // store in the position 0 value of count,  Read count = EEPROM.read(0);

  // stand by postion
  stand_by();
  
  // peep check
  peeps(3);

  // what kind of serial you are using?
  if(not myserial){
    Serial.println("From Serial: Robot Arm Hello!");
    }
  else{
    Serial.println("Communicate via mySerial");
    }
}
void loop() {
  if(myserial){
    mycomm();
    }
  else{
    comm();
    }
  }

void peep(){
  /*
   * a single peep function
   */
  digitalWrite(BZ,HIGH);
  delay(100); // delay 100 ms by sleep function
  digitalWrite(BZ,LOW);
  }

void peeps(int t){
  /*
   * multi peep function
   */
  for(int i=0;i<t;i++){
    peep();
    delay(100); // delay 100 ms by sleep function
    }
  }

void stand_by(){
  /*
  robot's arm go to standby posture
  */
  sv1.write(20);
  sv2.write(80);
  sv3.write(90);
  sv4.write(130); 
  }

void rotate(int pulses,int microTime,bool dir){
  /*
  robot's arm rotate a setup angle
  */
  // set limit for pulses
  if(pulses >1100){
    pulses = 1100;
    }
  // read count
  count = EEPROM.read(0);
  // accumulate count and store in pulse
  if(dir){
    count -= pulses;
    }
  else{
    count += pulses;
    }
  EEPROM.write(0,count);
  
  in_run = true;
  digitalWrite(enPin,0); // realse brake and go
  digitalWrite(dirPin,dir);
  
  for(int x = 0; x < pulses; x++) {
    digitalWrite(stepPin,HIGH); 
    delayMicroseconds(microTime); 
    digitalWrite(stepPin,LOW); 
    delayMicroseconds(microTime); 
   }
   
   digitalWrite(enPin,1); // brake
   in_run = false;
  }

void test_grip(){
  /*test servo grip*/
  sv4.write(150);
  delay(100);
  sv4.write(130);
  }
  
void test_step(){
  /*
   * test step motor function
  */
  rotate(100,1200,0);// forward
  delay(1000);
  rotate(100,1200,1);// backward      
  }

void forward(){
  /*
   * go forward 100 pulses
   */
   rotate(100,1200,0);// forward
  }

void backward(){
  /*
   * go backward 100 pulses
   */
   rotate(100,1200,1);// backward
  }

void flip_up(){
  rotate(400,1200,0);// forward
  while(in_run); // while step motor is runing don't run servo rc
  sv2.write(150);
  rotate(300,1200,0);
  while(in_run);
  sv2.write(180);
  rotate(500,1200,0);
  while(in_run);
  sv3.write(180);
  }

void lay_down(){
  
  sv3.write(90);
  delay(50);
  sv2.write(160);
  delay(50);
  rotate(200,1200,1);
  while(in_run);
  sv2.write(130);
  delay(100);
  rotate(200,1200,1);
  while(in_run);
  sv2.write(100);
  delay(100);
  rotate(200,1200,1);
  while(in_run);
  sv2.write(80);
  rotate(500,1200,1);
  }

void grip(){
  for(size_t i = 20;i<=60;i++){
    sv1.write(i);
    delay(5);
    }
  delay(1000);
  for(size_t i = 60;i>=20;i--){
    sv1.write(i);
    delay(5);
    }
  }
void say_hello(){
  flip_up();
  delay(2000);
  test_grip();
  delay(100);
  test_grip();
  delay(3000);
  grip();
  delay(3000);
  lay_down();
  delay(100);
  stand_by();
  }

void comm(){
  /*
   * communicate with robot's arm by serial built-in port 
   */
   if (Serial.available()){
    // get the serial string until q
    Val = Serial.readStringUntil('q'); // Accept 'q' not accept "q"??
    if(Val=="who"){
      Serial.println("arm");
      }
    else if(Val=="peeps"){
      peeps(5);
      }
    else if(Val=="grip"){
      test_grip();
      }
    else if(Val=="step"){
      test_step();
      }
    else if(Val=="forward"){
      forward();
      }
    else if(Val=="backward"){
      backward();
      }
    else if(Val=="up"){
      flip_up();
      }
    else if(Val=="down"){
      lay_down();
      }
    else if(Val=="hello"){
      say_hello();
      }
    else if(Val=="count"){
      count = EEPROM.read(0);
      Serial.println(count); // query the count value of step motor
      }
    else{
      Serial.println(Val);
      }
    }
  }

void mycomm(){
  /*
   * communicate with robot's arm by serial built-in port 
   */
   if (mySerial.available()){
    // get the serial string until q
    Val = mySerial.readStringUntil('q'); // Accept 'q' not accept "q"??
    if(Val=="who"){
      mySerial.println("arm");
      }
    else if(Val=="peeps"){
      peeps(5);
      }
    else if(Val=="grip"){
      test_grip();
      }
    else if(Val=="step"){
      test_step();
      }
    else if(Val=="forward"){
      forward();
      }
    else if(Val=="backward"){
      backward();
      }
    else if(Val=="up"){
      flip_up();
      }
    else if(Val=="down"){
      lay_down();
      }
    else if(Val=="hello"){
      say_hello();
      }
    else if(Val=="count"){
      count = EEPROM.read(0);
      mySerial.println(count); // query the count value of step motor
      }
    else{
      mySerial.println(Val);
      }
    }
  }

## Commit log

2022-04-28 add sensor signal
2022-04-29 edit robot arm code
    locchuong
2022-06-17 add install librealsense library in jetson nano
2022-06-17 issue 4 flowchart
2022-06-22 building util to teststream depth camera
2022-06-27 reset kill command after kill terminal
    [routes.py]
2022-06-30 return full frames for colorizer
2022-08-05 test step motor
2022-08-05 add code test blink led
2022-08-05 add code test servo motor
2022-08-05 building test step motor function
2022-08-05 build test stepper motor method
2022-08-05 building test steper motor
2022-08-05 building test stepper motor
2022-08-05 add test stepper motor
2022-08-05 add test stepper motor function
2022-08-05 building testing stepper motor function
2022-08-05 testing stepper motor
2022-08-06 building docs
    [cad.dwg]
2022-08-06 test robot arm
2022-08-06 buidling docs
    [cad.dwg]
2022-08-15 add design pin
    [pin.dwg]
2022-08-24 design harware
    [assembly.dwg, banh_xe.dwg, cad.dwg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]
2022-08-24 design hardware
    [banh_xe.dwg]
2022-08-27 build emoled
    [A.dwg, B.dwg, C.dwg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]
2022-08-29 add design
    [assembly.dwg, cut.dwg, head.dwg]
2022-08-29 testing camera
2022-08-30 build test camera utils
2022-08-30 building function test motor controller
2022-08-30 building test motor function
2022-08-30 building arm function
2022-09-07 add led declare led build in pin
2022-09-07 building robot arm function
2022-09-07 building arm
2022-09-07 add delay function test robot arm
2022-09-07 building testing arm function
2022-09-07 intergate arm motor and emoled into one object
2022-09-07 intergate arm motor and emoled
2022-09-07 intergate arm and emoled into manual function
2022-09-07 add reset into robot arm function
    [gpio.py]
2022-09-07 intergate arm and emoled done
2022-09-12 building init
    [config.txt]
2022-09-12 building library
    [config.txt]
2022-09-13 building arm function in manual control
2022-09-13 building manual control arm function
2022-09-13 add stream serial camera api
2022-09-13 builded stream serial-camera
2022-09-14 synchronized printing console
2022-09-14 synchornized printing out console
2022-09-23 add util streaming via socket

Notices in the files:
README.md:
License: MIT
